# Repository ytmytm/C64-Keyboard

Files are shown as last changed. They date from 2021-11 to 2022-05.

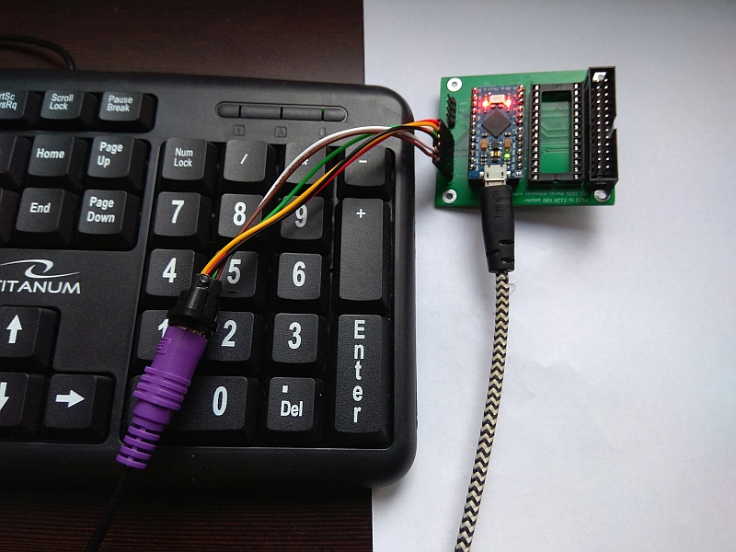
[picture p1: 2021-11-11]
PS2/C128_keyboard_MT8808/Photos/03.usb debugging.jpg

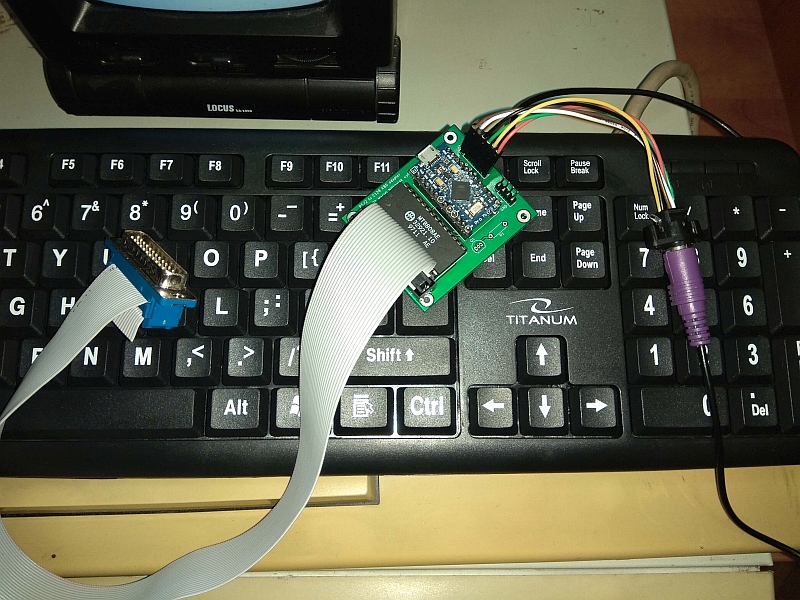
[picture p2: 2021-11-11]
PS2/C128_keyboard_MT8808/Photos/04.assembled.jpg

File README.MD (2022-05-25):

# C128 version

I have forked this version from https://github.com/Hartland/C64-Keyboard for two reasons:

- design PCB to connect PS/2 keyboard with MT8808 and Arduino Micro Pro solution to C128D, directly to the keyboard port
- provide symbolic, rather than positional, mapping for the keys

Everything you need for this version is in PS2/C128_keyboard_MT8808 folder.

I have cleaned up the code and added named key value definitions to the [keymap file](PS2/C128_keyboard_MT8808/Firmware/keymapping.h) for easier mapping.

Have fun!

-- Maciej 'YTM/Elysium' Witkowiak

## Project cloning

This project uses external submodule with Arduino Micro Pro symbol and footprint.

Clone it with all submodules using:

```sh
git clone --recurse-submodules https://github.com/ytmytm/C64-Keyboard.git
```

## PCB and schematic

Use KiCad to open the project in PS2/C128_keyboard_MT8808/PCB folder.

Ready for use Gerber files for circuit board v1.0 are in PS2/C128_keyboard_MT8808/PCB/gerber folder.

## Firmware

Use Arduino IDE to compile and flash the code from PS2/C128_keyboard_MT8808/Firmware folder.

## C128 PS/2 version circuit assembly

Parts:

* 26-wire flat ribbon cable
* 26-pin ribbon cable connectors (male for PCB, female for crimping on the cable)
* DE25 male crimp connector for ribbon cable
* MT8808
* Arduino Micro Pro
* (optional) PS/2 socket
* (optional) 28-pin and 24-pin sockets

Assembly:

* align red (first) wire with triangular mark on the female connector and crimp it
* separate 26th wire and remove it from the cable, cut it off as close as possible to the already crimped connector
* now the cable can be aligned and crimped in the DE25 connector; aligh red (first) wire with the mark on connector, confirm that it goes to pin 1
* solder parts on the PCB, start with lowest profile components first (sockets, MT8808, male 26-pin connector)

You can skip over transistor and resistor and connect pin 3 from the cable directly to Arduino pin 16 using a jumper.
This part would be required on C64, but C128 has separate circuitry for RESTORE key, it's not tied directly to /NMI line.

Add two wire connections that I forgot to put on PCB in version 1:

* pin 24 to A0 (40/80 key)
* pin 25 to A1 (CAPS key)

## Keyboard mapping

| C64/128 key | PS/2 key |
|---|---|
| C=		  | Windows  |
| RUN/STOP | ESC, END, left ALT |
| RESTORE | TAB |
| ARROW LEFT  | ` (tilde) |
| ARROW UP | ^ (SHIFT+6) |
| @ | @ (SHIFT+2) |
| DEL | DEL, BACKSPACE |
| CLR/HOME | HOME |
| * | * (SHIFT+8) |
| POUND | \ |

## Function keys

| PS/2 key | action |
|---|---|
| F9 | symbolic keymap (default) |
| F10 | positional keymap |
| F11 | C128 CAPS toggle |
| F12 | C128 40/80 toggle |
| CAPS LOCK | SHIFT LOCK toggle |
| SysRq | reset MT8808 |

## BUGS

Left (right too?) SHIFT release must be *after* shifted key release. Otherwise the shifted key is stuck until exact the same sequence is entered again.
It's quite annoying for '@' and ':'.

## TODOs

To do in PCB version 2:

* connect C128 40/80 line (pin 24) to A0
* connect C128 CAPS line (pin 25) to A1
* connect RESTORE line (pin 3) directly to pin 16, no need for transistor and resistor there (true for 5V Arduino, certainly not for SEEDUINO)
* correct parts alignment so that mounting holes are not obscured
* use PS/2 socket footprint
* use DB25 male socket footprint for direct connection
* use 1x25 footprint for C64 compatibility
* +5V jumper between Arduino VCC and +5V net (serial port, PS/2 port and DE25 pin 4)

To do for MT8812/MT8816 version:

* handle extra C128 keys using DE25 pins 21/22/23 (K0/K1/K2)

To do for SEEDUINO version:

* there is not enough pins, I/O expander or latch is needed, 74'595 is enough for this
* 3x transistor + 3x 10K resistor for /RESTORE, 40/80 and CAPS required

# Original documentation follows

## C64 PS2/USB Keyboard

This project is designed to allow a PS2/USB keyboard to be used with a Commodore 64 in place of the original Commodore keyboard.

Dependencies
------------
* PS2KeyAdvanced Arduino library for use with PS2 keyboard. Install through the IDE library manager

* SEEED XIAO uses slightly modified USBHOST Arduino library (C64_USB_Host_Library_SAMD). This directory will need to be copied into the Arduino library directory.

* SEEED XIAO will need its board driver installed into the Arduino IDE. See manufacturers instructions.

* DUE also uses a modified USBHOST library but it is included with the source and does not need to be installed in the library directory.

Hardware
--------
* Arduino Uno, Nano, DUE, or SEEED XIAO. SEEED XIAO or DUE required for USB keyboard

* MT8808, MT8812 or MT8816 Analog Switch Array

* 20 pin female header or male header with cable (PATA cable will work)

* Arduino shield PCB. 
	- Any universal PCB that will line up correctly

* PS2 keyboard 
	- matching socket or cut/strip and directly wire
	
* USB keyboard - **SEEED XIAO is highly recommended as the DUE is overkill for this project** 
	- Requires SEEED XIAO or DUE. In most cases, the SEED requires USB Type C to USB A or Micro Type B cable/adapter
	- Keyboards that connect through internal USB hubs are not supported.This is a limitation of the USBHost library
	- Restore (NMI) key requires a NPN transistor (2n3904 suggested) and resistor (10K)

Documents
---------

* KEYBIN.PDF
	- MT88XX AY/AX. These are the hard wired Commodore keyboard header position values used in keyboard mapping.
	- The position values are placed on the keymap where the PS2/USB keyboard value matches the Commodore key desired.
	- The AX2-1-0 AY2-1-0 and logic hole hole columns are for reference and not needed to make keymaps. 
	- The logic hole column only applies to the MT8812-16.
	
* DEFAULTKEY.TXT
	- Key map of special function keys (EX. C= key mapped to Windows key)
	
* USB_KEY_CODES.TXT
	- Public Domain copy of USB HID scan codes.
	
* Schematic PDF files
	- Include wiring charts and are located in the PS2 and USB folders under the appropriate board type
	- MT8808 and MT8812-16 are separate due to a different MT88xx pinouts 

Usage
-----

* PS2 keyboards use the PS2KeyAdvanced library.
	-Use Manage Library to search for and install PS2KeyAdvanced.

* USB Keyboards use the included modified USBHOST.

* Using the Arduino IDE upload the sketch: *C64_keyboard.ino* into your Arduino.

* **SYSTEM OPTIONS ARE LOCATED IN THE *C64KEYBOARD.H* HEADER FILE. THE MT8808 DEFINITION IS VERY IMPORTANT. SET TO TRUE IF USING A MT8808 OR FALSE IF USING MT8812-16.**

!!!POWER REQUIREMENTS!!!!
-------------------------

* The Arduino UNO, Nano, and SEEED can be powered from the C64 keyboard header Pin 4

* **The Arduino DUE CANNOT BE POWERED FROM PIN 4!! Use the + side of C10 (+10V) connected to the DUE barrel power connector instead.**

TODO
----

* Create spreadsheet/program to automatically create key maps

* Publish pre-compiled binary files

Version 1.00
-------------
* Updated and cleaned up all schematics and documents. All wiring charts are now on the schematics.

* DUE has been brought out of archive status and will be part of future updates.

Version 0.920
-------------
* Add SEEED XIAO board for USB keyboards

* Document DUE is for archive only

Version 0.911
-------------
* USB IDE library requirement removed

Version 0.91
------------
* USB module published

Version 0.9
------------
* Code rewrite using PS2KeyAdvanced library

* Several bugs have been fixed

* Speed and reliability have been greatly improved

* Up to 2 key maps can be stored and hot swapped with assigned keys (Default F9-F10)

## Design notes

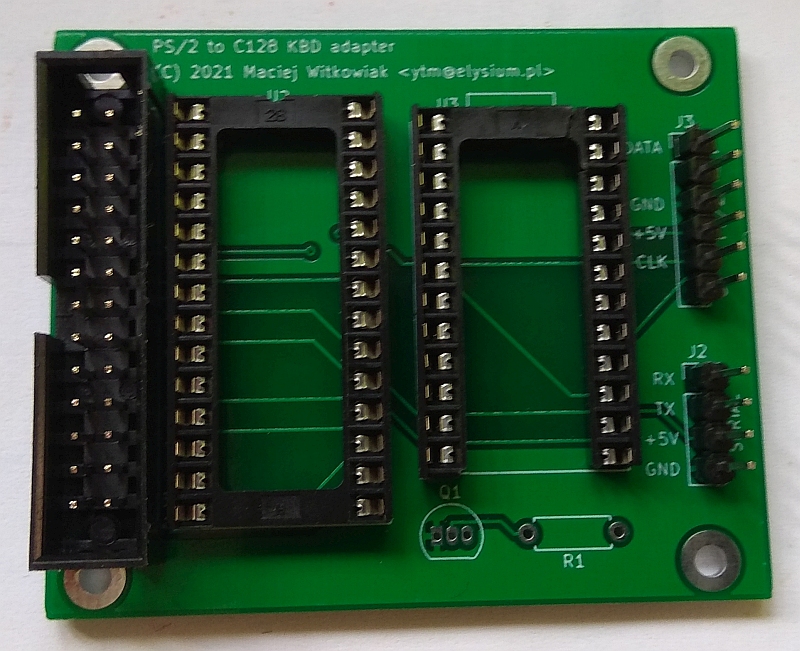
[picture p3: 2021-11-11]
PS2/C128_keyboard_MT8808/Photos/02.pcb.jpg

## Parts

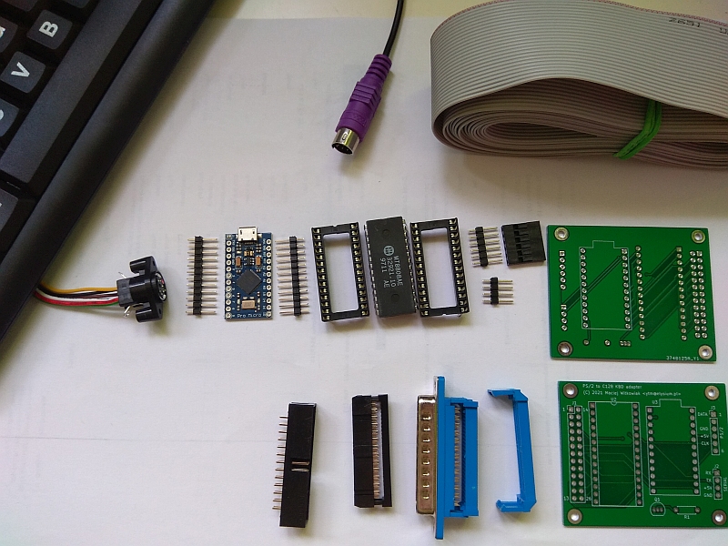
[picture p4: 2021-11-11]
PS2/C128_keyboard_MT8808/Photos/01.parts.jpg

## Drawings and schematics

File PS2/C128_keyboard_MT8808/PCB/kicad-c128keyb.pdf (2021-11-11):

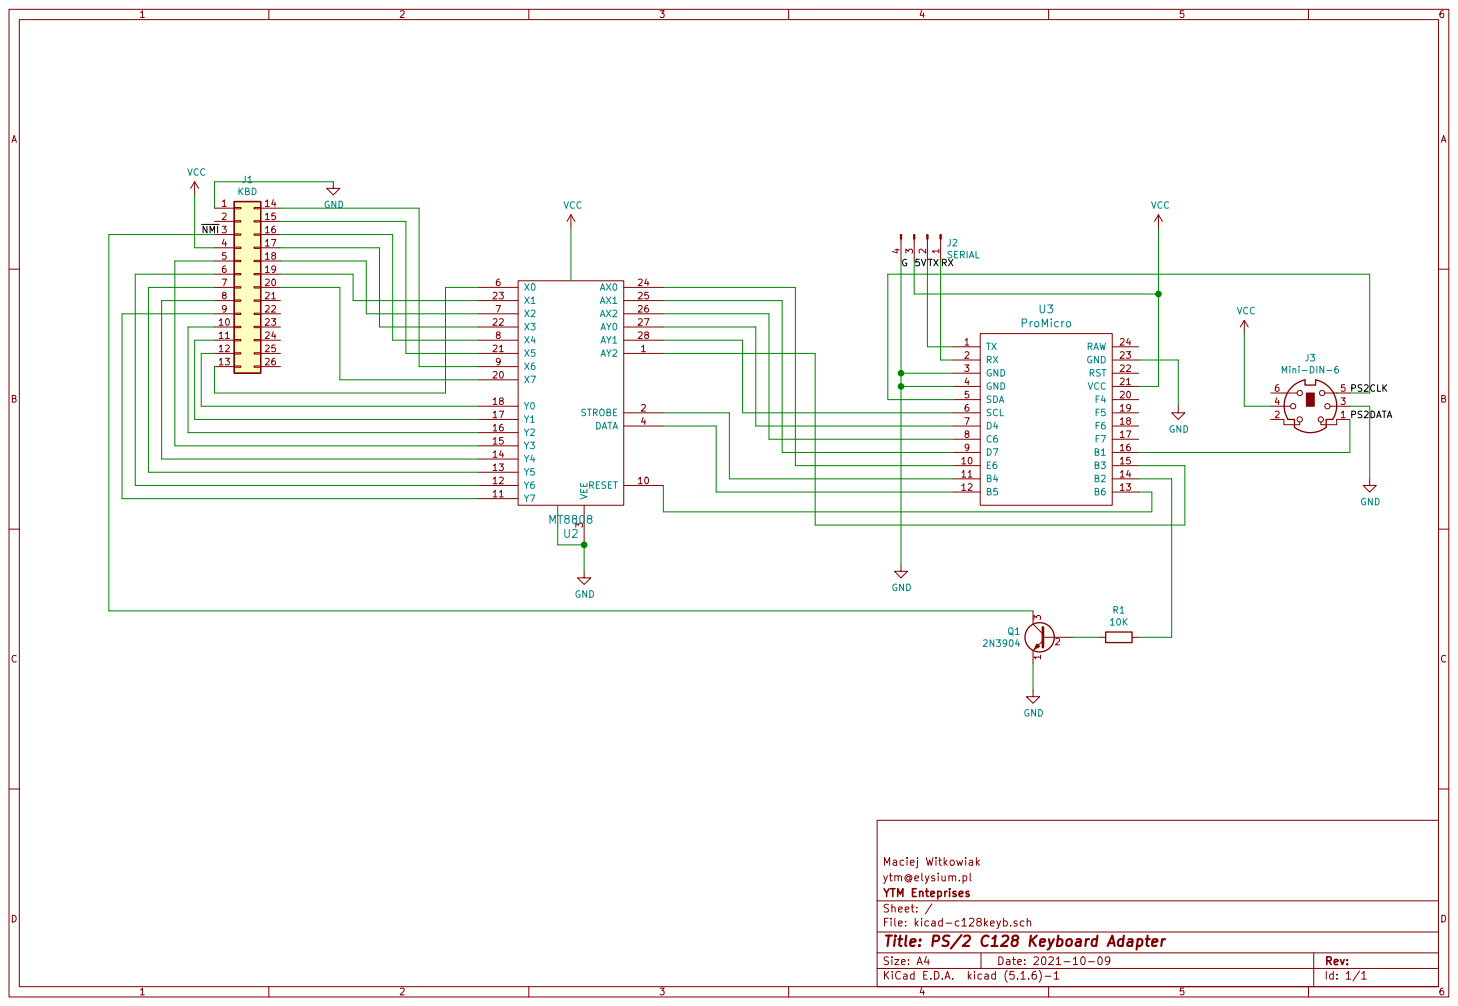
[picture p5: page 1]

Maciej Witkowiak
ytm@elysium.pl
File: kicad-c128keyb.sch Sheet: / YTM Enteprises

Id: 1/1 Title: PS/2 C128 Keyboard Adapter

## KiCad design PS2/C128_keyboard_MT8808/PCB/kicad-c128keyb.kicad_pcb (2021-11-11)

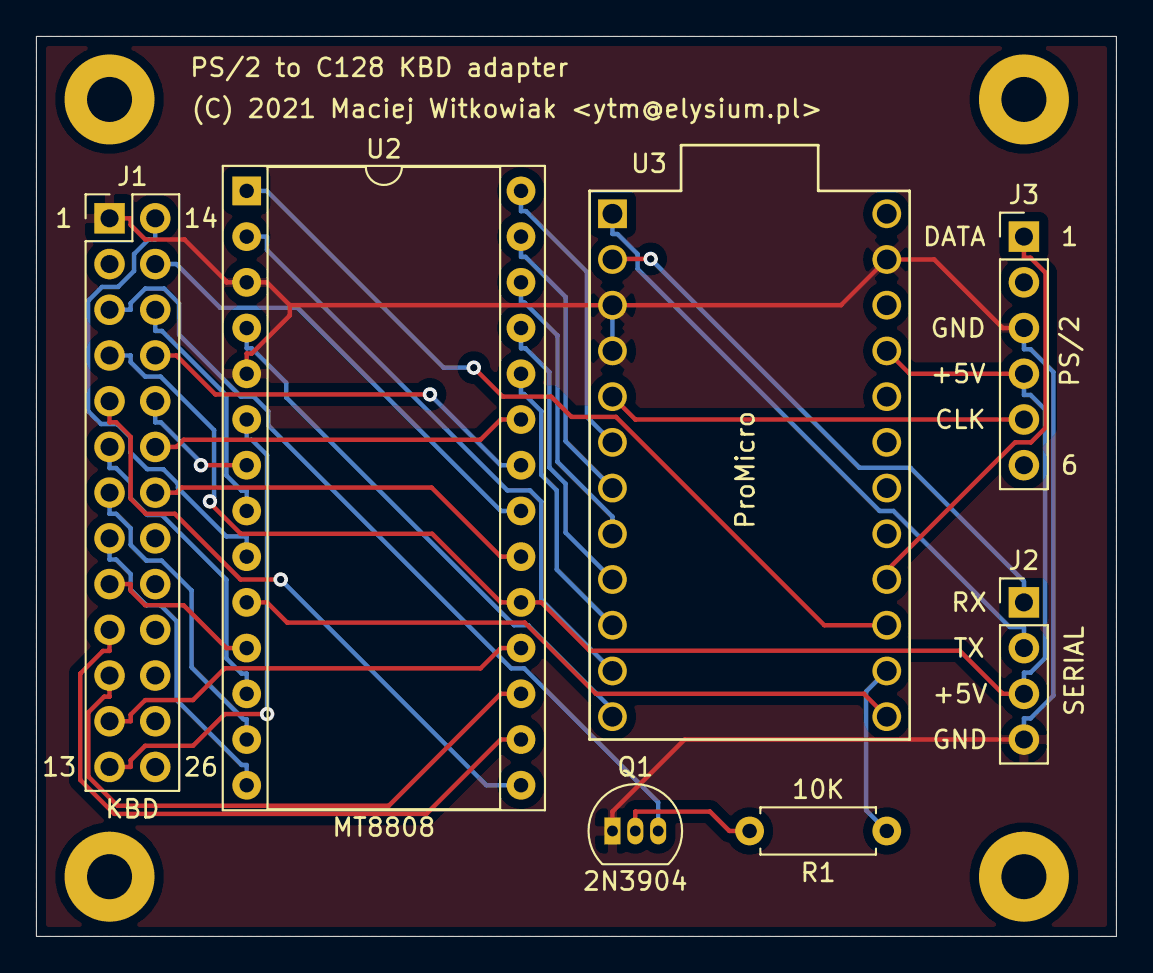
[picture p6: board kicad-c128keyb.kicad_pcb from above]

Board: 2 copper layers, 60.0 x 50.0 mm, 7 parts (0 on the bottom side), 34 nets.

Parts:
J1: KBD; Pin_Header_Straight_2x13_Pitch2.54mm
J2: SERIAL; Pin_Header_Straight_1x04_Pitch2.54mm
J3: Mini-DIN-6; Pin_Header_Straight_1x06_Pitch2.54mm
Q1: 2N3904; TO-92_Inline_Narrow_Oval
R1: 10K; R_Axial_DIN0207_L6.3mm_D2.5mm_P7.62mm_Horizontal
U2: MT8808; DIP-28_W15.24mm_Socket
U3: ProMicro

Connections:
/PS2CLK: J3.5, U3.5
/PS2DATA: J3.1, U3.16
/RX: J2.1, U3.2
/TX: J2.2, U3.1
/~NMI: J1.3, Q1.3
GND: J1.1, J2.4, J3.3, Q1.1, U2.3, U2.5, U3.3, U3.4, U3.23
unnamed: J1.5, U2.15
unnamed: J1.6, U2.12
unnamed: J1.7, U2.13
unnamed: J1.8, U2.14
unnamed: J1.9, U2.11
unnamed: J1.10, U2.16
unnamed: J1.11, U2.17
unnamed: J1.12, U2.18
unnamed: J1.13, U2.6
unnamed: J1.14, U2.9
unnamed: J1.15, U2.21
unnamed: J1.16, U2.8
unnamed: J1.17, U2.22
unnamed: J1.18, U2.7
unnamed: J1.19, U2.23
unnamed: J1.20, U2.20
unnamed: Q1.2, R1.2
unnamed: R1.1, U3.14
unnamed: U2.1, U3.15
unnamed: U2.2, U3.11
unnamed: U2.4, U3.12
unnamed: U2.10, U3.13
unnamed: U2.24, U3.10
unnamed: U2.25, U3.9
unnamed: U2.26, U3.8
unnamed: U2.27, U3.7
unnamed: U2.28, U3.6
VCC: J1.4, J2.3, J3.4, U2.19, U3.21

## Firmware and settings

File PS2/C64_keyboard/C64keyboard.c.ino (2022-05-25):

/*
  C64keyboard.h - Commodore Keyboard library

  Copyright (c) 2022 Hartland PC LLC
  Written by Robert VanHazinga


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
  You should have received a copy of the GNU Lesser General Public
  License along with this library; if not, write to the Free Software
  Foundation, Inc., 51 Franklin St, Fifth Floor, Boston, MA  02110-1301  USA
*/
#include "C64keyboard.h"



void resetMT88(void) {
  digitalWrite(ANALOG_SW_DATA , LOW);
  digitalWrite(ANALOG_SW_RESET, HIGH);
  digitalWrite( ANALOG_SW_STROBE, HIGH);
  digitalWrite(ANALOG_SW_RESET, LOW);
  digitalWrite( ANALOG_SW_STROBE, LOW);
  digitalWrite(ANALOG_SW_DATA , HIGH);
  keyboard.setLock (PS2_LOCK_SCROLL && 0);
  capslock = false;
  lshift = false;
  rshift = false;
  currkeymap = 1;
  }

void setswitch(uint8_t c){
  int bitr;
  bool state;
  // Fix logic table hole in MT8812/16
  // Convert x12 & x13 to x6 & x7. AX3 line control
  if ( !MT8808 &&( (c > 55 && c < 64) || (c > 23 && c < 32 ))) {
     c -= 24;
    digitalWrite(ANALOG_SW_AX3, HIGH);
  }
    
  if (c < 64) {
    for ( int currentPin = ANALOG_SW_ARRAY_START; currentPin <= ANALOG_SW_ARRAY_END; ++currentPin) {
      bitr = (currentPin - ANALOG_SW_ARRAY_START);
      state =  bitRead(c, bitr);
      digitalWrite(currentPin, state);
    }
    digitalWrite( ANALOG_SW_STROBE, HIGH);
    digitalWrite( ANALOG_SW_STROBE, LOW);
  }
  if (!MT8808){digitalWrite(ANALOG_SW_AX3, LOW);}

}

void debugkey (uint8_t c,uint8_t flags,uint8_t kc){
    Serial.print ("C64 Keycode: ");
    Serial.print (c);
    Serial.print ("  (ASCII Code: ");
    Serial.print (kc);
    Serial.print (" Hex: ");
    Serial.print (kc, HEX);
    Serial.print (")  Flags: ");
      for (int i = 7; i >= 0; i--)
    {
        bool b = bitRead(flags, i);
        Serial.print(b);
    }
    Serial.println();
  }
    
  

  
void c64key(uint16_t k) {
   flags = k >> 8;
   uint8_t kc= k & 0xFF;
   uint8_t c = 0;

  if (currkeymap == 2) {
    if (bitRead(flags, 6)) {
      c = pgm_read_byte(keymap->shift_2 + kc);
    }
    else {
      c = pgm_read_byte(keymap->noshift_2 + kc);
    }
  }


   if (currkeymap == 1) {
    if (bitRead(flags, 6)) {
      c = pgm_read_byte(keymap->shift_1 + kc);
    }
    else {
      c = pgm_read_byte(keymap->noshift_1 + kc);
    }
  }
//  debug output
    if (debug){debugkey(c,flags,kc);}

// Ignore extended codes 
    if (kc == PS2_KEY_ACK){c=IGNORE_KEYCODE;}
    
    
// MT reset function    
    if (kc == MT_RESET) {
    resetMT88();  
    c=IGNORE_KEYCODE;
   }   
   
// Restore key function   
    if (kc == RESTORE_KEY){
      if (bitRead (flags,7)){pinMode (NMI_PIN,INPUT);
     }
      if (!bitRead (flags,7)) {pinMode (NMI_PIN, OUTPUT);
        digitalWrite (NMI_PIN,LOW);
        }
      c = IGNORE_KEYCODE;
   }
   
// Capslock function 
    if (kc == CAPSLOCK_KEY) {
      capslock = !capslock;
      digitalWrite (ANALOG_SW_DATA, capslock);
      setswitch(C64_KEY_LSHIFT);
      c = IGNORE_KEYCODE; 
      }

// Keymap Handling
    if (kc == KEY_MAP_1 && !bitRead(flags,7)){
      currkeymap = 1;
      keyboard.setLock (PS2_LOCK_SCROLL && 0);
      }

    if (kc == KEY_MAP_2 && !bitRead(flags,7)){
      currkeymap = 2;
      keyboard.setLock (PS2_LOCK_SCROLL && 1);
      }
        
// Jump to end if key code is an ignored key
    if (c != IGNORE_KEYCODE) {
    // Differential shift conversion during key press
   if (c >= C64_MOD_SHIFT ) {
      c -= C64_MOD_SHIFT;
      if (rshift || lshift) {
        digitalWrite (ANALOG_SW_DATA, LOW);
        setswitch(C64_KEY_RSHIFT);
        digitalWrite (ANALOG_SW_DATA, LOW);
        setswitch(C64_KEY_LSHIFT);   
      }
      
     else {
        digitalWrite (ANALOG_SW_DATA, HIGH);
        setswitch(C64_KEY_LSHIFT);
      }
      // Set cross switch key
      digitalWrite(ANALOG_SW_DATA, HIGH);
      setswitch(c);
       if bitRead (flags,7){
      // Restore shift state to match keystate
      digitalWrite (ANALOG_SW_DATA, lshift);
      setswitch(C64_KEY_LSHIFT);
      digitalWrite (ANALOG_SW_DATA, rshift);
      setswitch(C64_KEY_RSHIFT);
      digitalWrite(ANALOG_SW_DATA, HIGH);
     }
   }
// Shift key handling
     if bitRead (flags,6){
   
      if (c == C64_KEY_RSHIFT) {rshift = true;}
      if (c == C64_KEY_LSHIFT) {lshift = true;}
      }
  
    if bitRead (flags,7){
      digitalWrite(ANALOG_SW_DATA , LOW);
        if (c==C64_KEY_RSHIFT) {rshift = false;}
        if (c==C64_KEY_LSHIFT) {lshift = false;}
        }
        
  // Process normal keypress
    if (c != IGNORE_KEYCODE){setswitch(c);}      
 }

// Reset switch state pin to default high state (Key press).
    digitalWrite(ANALOG_SW_DATA , HIGH);
}
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

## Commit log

2021-11-11 import of untracked project files
    [kicad-c128keyb-B_Cu.gbl, kicad-c128keyb-B_Mask.gbs, kicad-c128keyb-B_SilkS.gbo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]
2022-05-25 sync with origin https://github.com/Hartland/C64-Keyboard
    [KEYBIN.xlsx]
2022-05-27 PCB project with FLAT26 and DB25 + SEEEDUINO XIAO
    [kicad-c128keyb.kicad_sch, kicad-c128keyb.sch]

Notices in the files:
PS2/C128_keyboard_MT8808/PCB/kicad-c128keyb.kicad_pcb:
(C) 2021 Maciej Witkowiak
